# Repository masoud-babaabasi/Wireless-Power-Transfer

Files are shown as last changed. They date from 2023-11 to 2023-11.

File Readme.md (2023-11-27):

# A Wireless Power Transfer System
This is my master's degree project. The purpose of this project was to implement a wireless power transfer for a moving object for distances between 2 to 5 centimeters. This system also should compensate for angular misalignment in which the receiver coil plane has steep angles with the transmitting coils plane. All the coils for this project were implemented on PCB.
An array of 7 hexagon coils makes up the transmitting module. Each transmitter coil has a diameter of 5 centimeters and the receiver coil is a 3-centimeter square coil. For a better quality factor of the coils, the PCB coils are 2oz (70um) copper. 

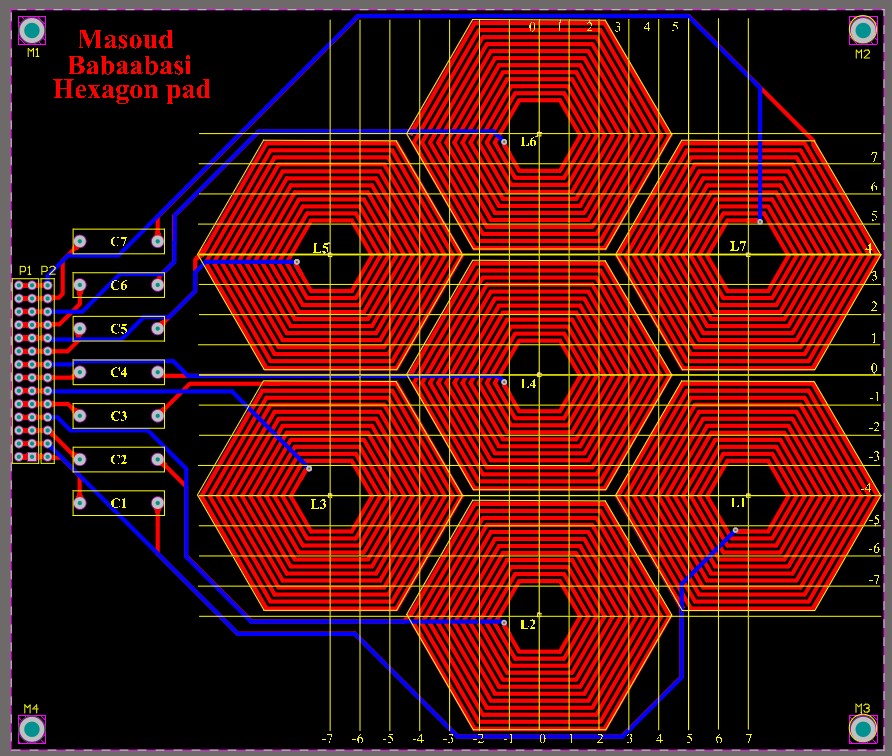
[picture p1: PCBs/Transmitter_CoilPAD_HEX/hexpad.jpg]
transmitter array


Painting all the coils in Altium Designer by hand is exhausting and complicated and making changes is even harder. So to automate routing, I used the Altium scripting feature. In Altium, you can write code in [DelphiScript](https://www.altium.com/documentation/altium-designer/writing-scripts) (*.pas), which is basically Pascal language. The Altium scrip project is in the `PCBs/Coil_drawing_script` folder. I have written several functions that draw different kinds of coils in a PCB document. In the picture below you can see some output examples of this script. With this script changing the parameters of the PCB coil such as width, spacing, number of turns, and output diameter of the coils is done very easily. You can access the functions in the `coil_script.pas` file.
```pascal
Procedure PlacePCBObjects;
Var
 CCW : Integer;
 L :  Integer;
 H :  Integer;
 w :  Integer;
 N :  Integer;
 s :  Integer;
 dis  : Integer;
Begin
    (*create a new pcb document *)
    WorkSpace := GetWorkSpace;
    If WorkSpace = Nil Then Exit;
    Workspace.DM_CreateNewDocument('PCB');

    If PCBServer = Nil Then Exit;
    Board := PCBServer.GetCurrentPCBBoard;
    If Board = Nil then exit;
    dis := 60;
    (* Place new PCB objects*)
     coilSpiralCW(50 , 5 , 0.9 , 0.3, dis , dis,eTopLayer,1);
     coilSpiralCCW(50 , 15 , 1.2 , 0.25, dis * 2 ,dis,eBottomLayer,1);
     coilHexagonCW(50 , 21 , 1 , 0.35, dis  * 3,dis ,eTopLayer ,1);
     CCW := 0;
     coilNside(4, 50 ,15 , 1 , 0.35, dis  * 4,dis ,CCW,Pi/4,eTopLayer , 1);
     coilSpiral(15 ,10 , 1 , 0.35, 1 ,dis  * 5,dis ,CCW , 0 ,eTopLayer , 1);
     CCW := 1;
     coilNside(5, 50 ,15 , 1 , 0.35, dis  ,dis * 2 ,CCW,7*pi/10,eTopLayer , 1);
     L := 50;
     N := 8;
     w := 1;
     s := 0.35;
     H := ( L - ( w + s ))/2 ;
     coilRECT_CW(L , H , N , w , s , dis * 2 ,dis * 2 , 1, eTopLayer , 1);
     coilRECT_CW(L , H , N , w , s , dis * 2 ,dis * 2 + H  + w + s  , 4 ,eTopLayer , 1);

     coilRECT_CCW(H , L , N , w , s, dis * 2 - (H+w+s)/2 ,dis * 2 + (H+w+s)/2 , 2 ,eBottomLayer , 1);
     coilRECT_CCW(H , L , N , w , s, dis * 2 - (H+w+s)/2 + H  + w + s ,dis * 2 + (H+w+s)/2, 1 ,eBottomLayer , 1);
     
     L := 30;
     N := 3;
     w := 3;
     coilRECT_CW(L , L , N , w , s , dis * 3 ,dis * 2 , 1, eTopLayer , 1);

    (* Refresh PCB workspace *)
    ResetParameters;
    AddStringParameter('Action', 'All');
    RunProcess('PCB:Zoom');
End;
```

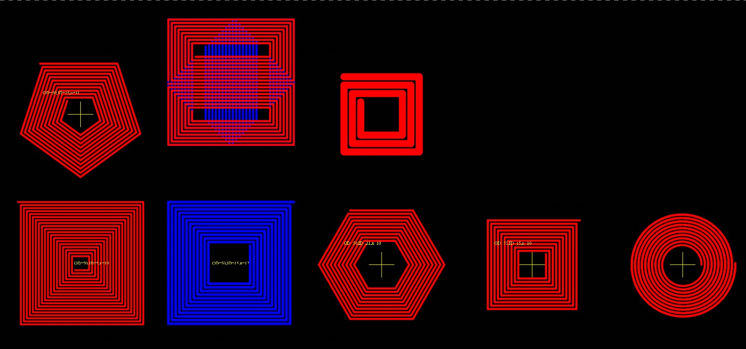
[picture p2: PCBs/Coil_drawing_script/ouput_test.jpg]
coils_altium


For driving the transmitter coils, 7 independent class D power amplifiers are implemented. The clock signals of these amplifiers are generated by an STM32F429 running at 180 MHz. Fourteen clock signals are produced and all of the amplifiers can be controlled independently.

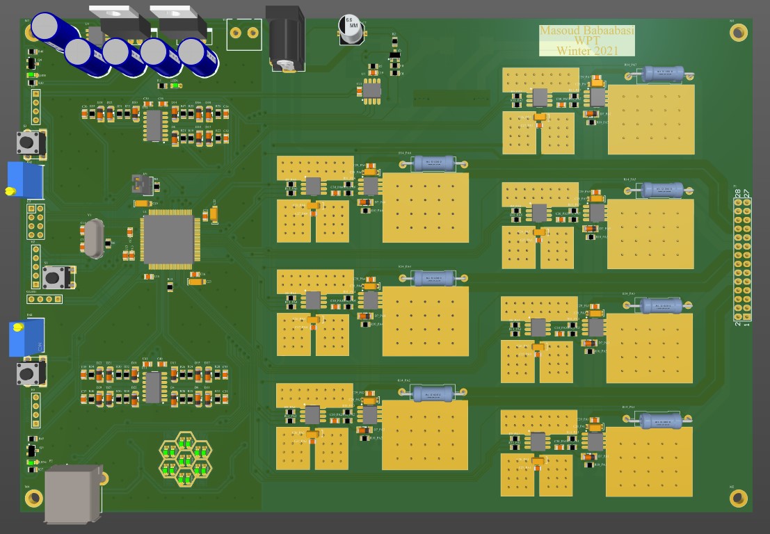
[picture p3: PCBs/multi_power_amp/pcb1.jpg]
power amps


On the receiver module, an ESP32 measures the voltage and current of the receiver circuit and transmits the data over Bluetooth Low Energy (BLE) to the transmitter module.

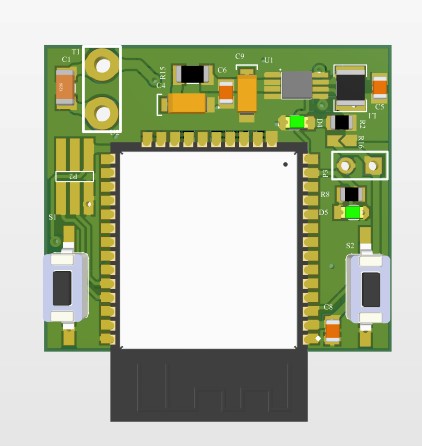
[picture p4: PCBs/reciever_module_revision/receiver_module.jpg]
receiver


ALL the coding for the transmitter module STM32F429 is done in Keil IDE. Four timers are used and all of them are configured to be in a slave-master situation which guarantees the synchronization of the clock signal.

A closed-loop algorithm is developed in Matalb to control the transmitter module based on data received over BLE.

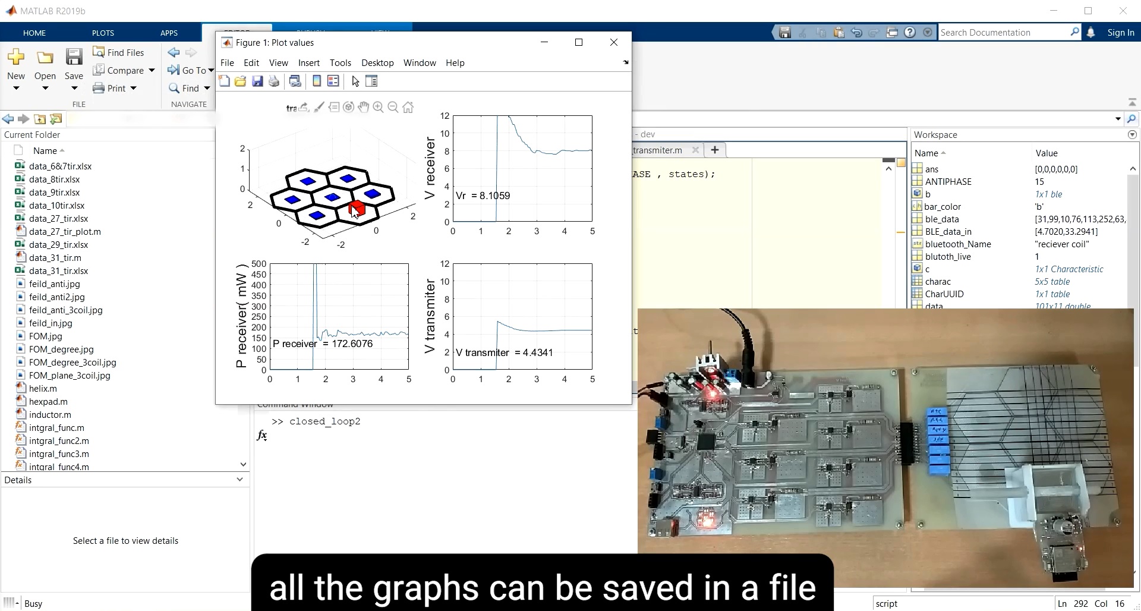
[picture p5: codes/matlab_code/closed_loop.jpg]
closed loop


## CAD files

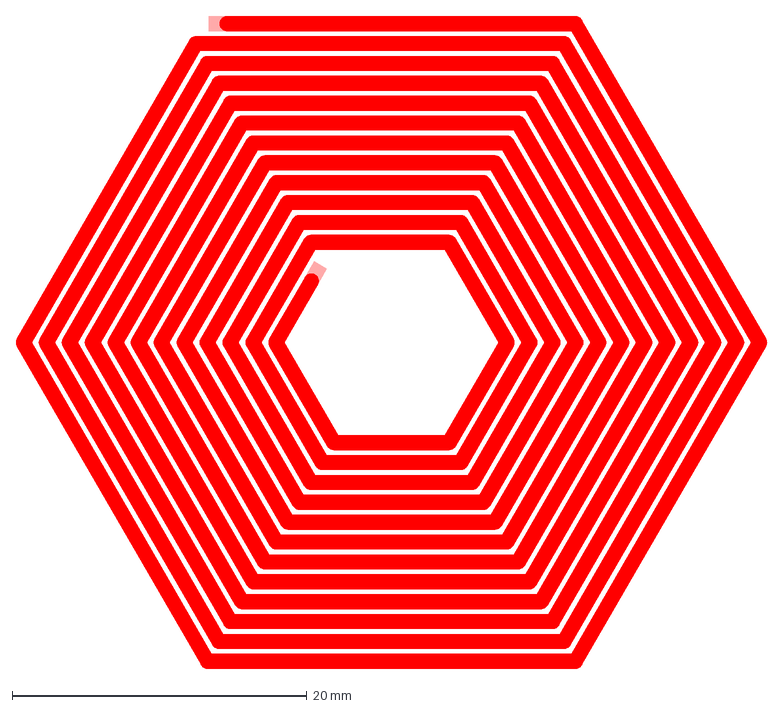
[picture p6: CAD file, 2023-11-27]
PCBs/Transmitter_CoilPAD_HEX/coil_hex.DXF
51.0 x 44.3 mm

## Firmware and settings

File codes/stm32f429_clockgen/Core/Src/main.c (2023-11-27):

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
/* Includes ------------------------------------------------------------------*/
#include "main.h"

ADC_HandleTypeDef hadc1;

SPI_HandleTypeDef hspi2;
SPI_HandleTypeDef hspi3;

TIM_HandleTypeDef htim1;
TIM_HandleTypeDef htim2;
TIM_HandleTypeDef htim3;
TIM_HandleTypeDef htim4;
TIM_HandleTypeDef htim5;
TIM_HandleTypeDef htim8;

UART_HandleTypeDef huart5;
UART_HandleTypeDef huart7;

/* USER CODE BEGIN PV */
#define RED 1
#define GREEN 0
#define ch1_2 1
#define ch3_4 3
#define INPHASE 1
#define OFF 0
#define ANTIPHASE -1
#define SHORTCIRCUIT 0
#define OPENCIRCUIT 1
	
TIM_TypeDef  *timers[7] = {TIM1,TIM2,TIM4,TIM4,TIM3,TIM3,TIM2};
const uint8_t channels[7] ={1,3,1,3,1,3,1};
uint16_t freq = 65;
uint8_t deadtime = 8;
float voltage = 4;
int8_t transmiter_state[7]={OFF,OFF,OFF,OFF,OFF,OFF,OFF};
uint16_t LEDs_state = 0;
uint8_t flags = 6;
//FATFS USBDISKFatFs;           /* File system object for USB disk logical drive */
//FIL MyFile;                   /* File object */
//char USBDISKPath[4];          /* USB Host logical drive path */
//USBH_HandleTypeDef hUSBHost; /* USB Host handle */
//static void MSC_Application(void);
//extern ApplicationTypeDef Appli_state;
char buff[5];
char received_flag = 0;
/* USER CODE END PV */

void SystemClock_Config(void);
static void MX_GPIO_Init(void);
static void MX_ADC1_Init(void);
static void MX_SPI2_Init(void);
static void MX_SPI3_Init(void);
static void MX_TIM1_Init(void);
static void MX_TIM2_Init(void);
static void MX_TIM3_Init(void);
static void MX_TIM4_Init(void);
static void MX_UART5_Init(void);
static void MX_UART7_Init(void);
static void MX_TIM5_Init(void);
static void MX_TIM8_Init(void);
/* USER CODE BEGIN PFP */
void timers_init();
void setRegVoltage(float Vo);
void resetLEDs();
void setLEDs(uint8_t COL, uint8_t NUM , uint8_t ON_OFF );
void set_frequency(int f);
void PWM_SET(TIM_HandleTypeDef* timer, uint8_t channel ,int8_t phase,int f,uint8_t deadtime);
void transmiter(uint8_t num,int8_t state , uint8_t HighZ);
/* USER CODE END PFP */

/* USER CODE BEGIN 0 */
	union transmit_data
    {
    uint16_t ADCValue[7];
    uint8_t TXdata[14];
    }TData;

/* USER CODE END 0 */

/**
  * @brief  The application entry point.
  * @retval int
  */
int main(void)
{
  /* MCU Configuration--------------------------------------------------------*/

  /* Reset of all peripherals, Initializes the Flash interface and the Systick. */
  HAL_Init();

  /* Configure the system clock */
  SystemClock_Config();

  /* Initialize all configured peripherals */
  MX_GPIO_Init();
  MX_ADC1_Init();
  MX_SPI2_Init();
  MX_SPI3_Init();
  MX_TIM1_Init();
  MX_TIM2_Init();
  MX_TIM3_Init();
  MX_TIM4_Init();
  MX_UART5_Init();
  MX_UART7_Init();
  MX_TIM5_Init();
  MX_TIM8_Init();
  /* USER CODE BEGIN 2 */
	resetLEDs();
//	__HAL_RCC_TIM2_CLK_ENABLE();
//	TIM2->CR1 = (1<<0)|(1<<5)|(1<<6);
//	TIM2->CCMR1 = (1<<5)|(1<<6)|(1<<14)|(1<<13);
//	TIM2->CCER = (1<<0)|(1<<4);
//	TIM2->ARR = freq;
//	TIM2->CCR1 = (freq/2)-5;
//	TIM2->CCR2 = (freq/2)+5;
//	__HAL_RCC_GPIOB_CLK_ENABLE();
//  __HAL_RCC_GPIOA_CLK_ENABLE();
//	GPIO_InitTypeDef GPIO_InitStruct = {0};
//	GPIO_InitStruct.Pin = GPIO_PIN_3;
//    GPIO_InitStruct.Mode = GPIO_MODE_AF_PP;
//    GPIO_InitStruct.Pull = GPIO_NOPULL;
//    GPIO_InitStruct.Speed = GPIO_SPEED_FREQ_LOW;
//    GPIO_InitStruct.Alternate = GPIO_AF1_TIM2;
//    HAL_GPIO_Init(GPIOB, &GPIO_InitStruct);

//    GPIO_InitStruct.Pin = GPIO_PIN_15;
//    GPIO_InitStruct.Mode = GPIO_MODE_AF_PP;
//    GPIO_InitStruct.Pull = GPIO_NOPULL;
//    GPIO_InitStruct.Speed = GPIO_SPEED_FREQ_LOW;
//    GPIO_InitStruct.Alternate = GPIO_AF1_TIM2;
//    HAL_GPIO_Init(GPIOA, &GPIO_InitStruct);
	//RCC->APB1ENR = RCC->APB1ENR |(uint32_t)(1<<0);
	
	
	
//	for(int i=1 ; i<=7 ; i++) {
//		if(i>1) setLEDs(RED,i-1,0);
//		setLEDs(RED,i,1);
//		HAL_Delay(100);
//	}
//	setLEDs(RED,7,0);
//	for(int i=1 ; i<=7 ; i++){
//		if(i>1) setLEDs(GREEN,i-1,0);
//		setLEDs(GREEN,i,1);
//		HAL_Delay(100);
//	}
//	setLEDs(GREEN,7,0);
  /* USER CODE END 2 */

  /* Infinite loop */
  /* USER CODE BEGIN WHILE */
	//int i;
	timers_init();
	HAL_GPIO_WritePin(REG_ON_GPIO_Port,REG_ON_Pin,GPIO_PIN_SET);
	HAL_GPIO_WritePin(POT_CS_GPIO_Port,POT_CS_Pin,GPIO_PIN_SET);
	HAL_Delay(100);
	setRegVoltage(4);
	/*for(i=3;i<=12;i++) {
		setRegVoltage(i);
		HAL_Delay(500);
	}*/
	//PWM_SET(&htim4 ,ch3_4 , ANTIPHASE ,64 , 7);
	//PWM_SET(&htim2 ,ch3_4 , INPHASE ,64 , 7);
	/*for(int i =1 ; i <= 7 ; i++){
			transmiter(i,ANTIPHASE);
		if(i>1) transmiter(i-1,OFF);
		HAL_Delay(2000);
	}*/
	//HAL_TIM_Base_Stop(&htim1);
	//HAL_TIM_Base_Stop(&htim2);
	//HAL_TIM_Base_Stop(&htim3);
	//HAL_TIM_Base_Stop(&htim4);
	HAL_Delay(200);
	//transmiter(2,INPHASE);
	HAL_Delay(20);
	transmiter(6,ANTIPHASE,OPENCIRCUIT);
//	char tx_state = 'S';
//	buff[0] = 'S';
	set_frequency(102);
	//transmiter(6,ANTIPHASE);
	//transmiter(7,ANTIPHASE);
	HAL_TIM_PWM_Start(&htim1, TIM_CHANNEL_1);
	HAL_TIM_PWM_Start(&htim1, TIM_CHANNEL_2);	
	//HAL_TIM_Base_Start(&htim1);
	TIM1->CR1 |= (1<<0);
	TIM5->CR1 |= (1<<0);
	
	HAL_TIM_Base_Start(&htim8);
	HAL_TIM_Base_Start(&htim1);
	HAL_TIM_PWM_Start(&htim1, TIM_CHANNEL_1);
	HAL_TIM_PWM_Start(&htim1, TIM_CHANNEL_2);	
	//HAL_TIM_PWM_Start(&htim4, TIM_CHANNEL_3);
	//HAL_TIM_PWM_Start(&htim4, TIM_CHANNEL_4);		

	float v = 4;
	
	uint16_t f=0;
	//unsigned int ADCValue[9];
	uint8_t i=0;
	//Appli_state = APPLICATION_START;
	HAL_UART_Receive_IT(&huart5,(uint8_t *)buff, 2);
	//void *packetADD = &(ADCValue[0]);
  while (1)
  {
		/*HAL_GPIO_TogglePin(LED1_GPIO_Port,LED1_Pin);
		HAL_Delay(500);
		HAL_GPIO_TogglePin(LED2_GPIO_Port,LED2_Pin);
		HAL_Delay(500);*/
		/*setRegVoltage(v);
		if(f){
			v = v + 0.5;
			if(v==10) f=0;
		}
		else{
			v = v - 0.5;
			if(v==3) f=1;
		}
		HAL_Delay(500);*/
/*************** ADC start conversion*******************************/
		/*HAL_ADC_Start(&hadc1);
		for(i=0;i<10;i++){
			if (HAL_ADC_PollForConversion(&hadc1, 100) == HAL_OK){
					TData.ADCValue[i] = HAL_ADC_GetValue(&hadc1);
			}
		}
		HAL_UART_Transmit (&huart5, TData.TXdata ,2*7,10);*/
		//HAL_Delay(10);

/**************UART input data interpatation*************************/		
		if(received_flag){
				received_flag = 0;
				if( buff[0] == 'f' || buff[0] == 'F' ){
					freq = ( (uint8_t)buff[1] );
					set_frequency(freq);
				}else if( buff[0] == 'v' || buff[0] == 'V' ){
					voltage = (( uint8_t)buff[1] ) * 10 / 255.0 + 1.9;
					setRegVoltage( voltage );
				}
				else if( buff[0] == 't' || buff[0] == 'T' ){
					flags = (( uint8_t)buff[1] )  & ( 0x0f );
					transmiter_state[ flags - 1 ] = (int8_t) ( ( uint8_t)buff[1]  & ( 0xf0 ) ) >> 4 ;
					transmiter( flags , transmiter_state[ flags - 1 ] , OPENCIRCUIT );
				}
				else if( buff[0] == 'S' && buff[1] == 'C' ){ //start conversion command
					HAL_ADC_Start(&hadc1);
					for(i=0;i<10;i++){
						if (HAL_ADC_PollForConversion(&hadc1, 100) == HAL_OK){
								TData.ADCValue[i] = HAL_ADC_GetValue(&hadc1);
						}
					}
					HAL_UART_Transmit (&huart5, TData.TXdata ,2*7,10);
				}
}
/*******************frequency setting**********************************/
//		f = TData.ADCValue[3] /(2047.0) * 80 + 50 ;
//		if( f != freq){
//			freq = f;
////			HAL_TIM_Base_Stop(&htim8);
////			HAL_TIM_Base_Stop(&htim5);
////			HAL_TIM_Base_Stop(&htim1);
////			HAL_TIM_Base_Stop(&htim2);
////			HAL_TIM_Base_Stop(&htim3);
////			HAL_TIM_Base_Stop(&htim4);
//			set_frequency(f);
////			HAL_TIM_Base_Start(&htim8);
////			HAL_TIM_Base_Start(&htim5);
//		}

/********************************voltage set****************************/
//		v = TData.ADCValue[4] / (2047.0)  * 8.0  + 4.0;
//		if(v != voltage ) {
//			voltage = v;
//			setRegVoltage(v);
//		}
		HAL_Delay(10);
		
/********************** transmiter number set *************************/
//		if( HAL_GPIO_ReadPin(PB2_GPIO_Port,PB2_Pin) == GPIO_PIN_RESET){
//			flags++;
//			if(flags>= 8 ) flags =6;
//			transmiter(flags,ANTIPHASE,OPENCIRCUIT);
//			/*if(flags == 0 ) {
//				transmiter(7,ANTIPHASE);
//				flags =1;
//			}
//			else if(flags == 1 ) {
//				transmiter(7,INPHASE);
//				flags =2;
//			}else if(flags == 2 ) {
//				transmiter(7,OFF);
//				flags =0;
//			}*/
//			/*flags++;
//			if(flags==8)flags = 1;
//			if(flags == 1) transmiter(7,OFF);
//			else transmiter(flags-1,OFF);
//			transmiter(flags,ANTIPHASE);*/
//			HAL_Delay(300);
//		}
/******************* transmiter state set*****************************/
//		if( HAL_GPIO_ReadPin(PB1_GPIO_Port,PB1_Pin) == GPIO_PIN_RESET){
//			int8_t st = transmiter_state[flags-1];
////			st++;
////			if(st == 2) st = -1;
//			st--;
//			if(st <= -2) st = 1;
//			transmiter(flags,st,OPENCIRCUIT);
//			HAL_Delay(300);	
//		}
    /* USER CODE END WHILE */

    /* USER CODE BEGIN 3 */
  }
  /* USER CODE END 3 */
}

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
/* USER CODE BEGIN 4 */
/********************************************************************************************/
void timers_init(){
	TIM1->CCER &= ~((1 << 0) | (1 << 4) | (1 << 8) | (1 << 12) );
	TIM2->CCER &= ~((1 << 0) | (1 << 4) | (1 << 8) | (1 << 12) );
	TIM3->CCER &= ~((1 << 0) | (1 << 4) | (1 << 8) | (1 << 12) );
	TIM4->CCER &= ~((1 << 0) | (1 << 4) | (1 << 8) | (1 << 12) );
	
	TIM1->CR1 |= (1<<0);
	TIM2->CR1 |= (1<<0);
	TIM3->CR1 |= (1<<0);
	TIM4->CR1 |= (1<<0);
}
/********************************************************************************************/
void setRegVoltage(float Vo){
	uint16_t pData;
	//pData = 0x11;
//	if( Vo >=2.717 && Vo <= 12) pData = 1.482/(Vo-1.235)*256.00;
//	else if( Vo < 2.717 ) pData = 255;
//	else if( Vo > 12 ) pData = 35;
	if( Vo >=1.9 && Vo <= 12) pData = 4.7*1.23*256.0/10.0/(Vo-1.23);
	else if( Vo < 1.9 ) pData = 255;
	else if( Vo > 12 ) pData = 14;
	pData = pData | (uint16_t)(0x11 << 8) ;
	HAL_GPIO_WritePin(POT_CS_GPIO_Port,POT_CS_Pin,GPIO_PIN_RESET);
	HAL_SPI_Transmit(&hspi2,(uint8_t *)&pData,1,100);
	HAL_GPIO_WritePin(POT_CS_GPIO_Port,POT_CS_Pin,GPIO_PIN_SET);
  /* USER CODE END UART7_Init 2 */

}

/********************************************************************************************/
void resetLEDs(){
	uint8_t LED_data1 = 0x00;
	HAL_SPI_Transmit(&hspi3,(uint8_t *)&LED_data1,1,100);
	HAL_SPI_Transmit(&hspi3,(uint8_t *)&LED_data1,1,100);
	HAL_Delay(1);
	HAL_GPIO_WritePin(REG_clk_GPIO_Port,REG_clk_Pin,GPIO_PIN_SET);
	HAL_Delay(1);
	HAL_GPIO_WritePin(REG_clk_GPIO_Port,REG_clk_Pin,GPIO_PIN_RESET);
}
/********************************************************************************************/
void setLEDs(uint8_t COL, uint8_t NUM , uint8_t ON_OFF ){
		uint16_t d = 0 ;
		if( NUM <= 7 && NUM >= 1 && (COL == RED || COL == GREEN)){
			d = 1 << (LED_POS[NUM-1]*2 + COL);
			if(ON_OFF == 1) LEDs_state |= d;
			else if(ON_OFF == 0) LEDs_state &= ~d;			 
			uint8_t LED_data1 = LEDs_state & 0xff;
			uint8_t LED_data2 = LEDs_state >> 8;
			HAL_SPI_Transmit(&hspi3,&LED_data1,1,100);
			HAL_SPI_Transmit(&hspi3,&LED_data2,1,100);
			HAL_Delay(1);
			HAL_GPIO_WritePin(REG_clk_GPIO_Port,REG_clk_Pin,GPIO_PIN_SET);
			HAL_Delay(1);
			HAL_GPIO_WritePin(REG_clk_GPIO_Port,REG_clk_Pin,GPIO_PIN_RESET);
		}
}
/********************************************************************************************/
void set_frequency(int f){
	TIM1->ARR = f;
	TIM2->ARR = f;
	TIM3->ARR = f;
	TIM4->ARR = f;
	for(int i=0;i<7;i++){
		if( channels[i] == ch1_2){
			timers[i]->CCR1 = (uint16_t)(f / 2)-transmiter_state[i]*deadtime;
			timers[i]->CCR2 = (uint16_t)(f / 2)+ transmiter_state[i]*deadtime;
		}else if( channels[i] == ch3_4){
			timers[i]->CCR3 = (uint16_t)(f / 2)- transmiter_state[i]*deadtime;
			timers[i]->CCR4 = (uint16_t)(f / 2)+ transmiter_state[i]*deadtime;
		}
	}
}
/********************************************************************************************/
void PWM_SET(TIM_HandleTypeDef* timer,uint8_t channel ,int8_t phase ,int f,uint8_t deadtime)
{
//	timer->Init.Period = f;
//	HAL_TIM_PWM_Init(timer);
//	TIM_OC_InitTypeDef sConfigOC = {0};
//	sConfigOC.OCPolarity = TIM_OCPOLARITY_HIGH;
//  sConfigOC.OCFastMode = TIM_OCFAST_ENABLE;

	//sConfigOC.Pulse = (uint16_t)(f / 2);

//	if( phase == INPHASE) sConfigOC.OCMode = TIM_OCMODE_PWM1;
//  else if( phase == ANTIPHASE) sConfigOC.OCMode = TIM_OCMODE_PWM2;
//  sConfigOC.Pulse = (int)(f / 2) - (phase)*deadtime;
//	if(channel == ch1_2) HAL_TIM_PWM_ConfigChannel(timer, &sConfigOC, TIM_CHANNEL_1);
//	else if(channel == ch3_4) HAL_TIM_PWM_ConfigChannel(timer, &sConfigOC, TIM_CHANNEL_3);
//  sConfigOC.Pulse = (int)(f / 2) + (phase)*deadtime;
//	if(channel == ch1_2) HAL_TIM_PWM_ConfigChannel(timer, &sConfigOC, TIM_CHANNEL_2);
//	else if(channel == ch3_4) HAL_TIM_PWM_ConfigChannel(timer, &sConfigOC, TIM_CHANNEL_4);
  	HAL_TIM_MspPostInit(timer);
}
/********************************************************************************************/
void transmiter(uint8_t num,int8_t state , uint8_t HighZ)
{
	uint16_t temp;
	if(state == INPHASE ){
			if(channels[num-1] == ch1_2){
			timers[num-1]->CCER &= ~((1 << 0) | (1 << 4));
			timers[num-1]->CCMR1 |= ((1<<5)|(1<<6)|(1<<13)|(1<<14));
			timers[num-1]->CCMR1 &= ~((1<<4)|(1<<12));//pwm mode1
			timers[num-1]->CCR1 = (uint16_t)(freq / 2)- state*deadtime;
			timers[num-1]->CCR2 = (uint16_t)(freq / 2)+ state*deadtime;
			timers[num-1]->CCER |= ((1 << 0) | (1 << 4));//output enable
			}else if(channels[num-1] == ch3_4){
			timers[num-1]->CCER &= ~((1 << 8) | (1 << 12));
			timers[num-1]->CCMR2 |= ((1<<5)|(1<<6)|(1<<13)|(1<<14));
			timers[num-1]->CCMR2 &= ~((1<<4)|(1<<12));//pwm mode1
			timers[num-1]->CCR3 = (uint16_t)(freq / 2)- state*deadtime;
			timers[num-1]->CCR4 = (uint16_t)(freq / 2)+ state*deadtime;
			timers[num-1]->CCER |= ((1 << 8) | (1 << 12));//output enable
			}
			setLEDs(RED , num , 1);
			setLEDs(GREEN , num , 0);
	}else if(state == ANTIPHASE ){
		 if(channels[num-1] == ch1_2){
			timers[num-1]->CCER &= ~((1 << 0) | (1 << 4));
			timers[num-1]->CCMR1 |= ((1<<4)|(1<<5)|(1<<6)|(1<<12)|(1<<13)|(1<<14));//pwm mode2
			timers[num-1]->CCR1 = (uint16_t)(freq / 2)- state*deadtime;
			timers[num-1]->CCR2 = (uint16_t)(freq / 2)+ state*deadtime;
			timers[num-1]->CCER |= ((1 << 0) | (1 << 4));//output enable
			}else if(channels[num-1] == ch3_4){
			timers[num-1]->CCER &= ~((1 << 8) | (1 << 12));
			timers[num-1]->CCMR2 |= ((1<<4)|(1<<5)|(1<<6)|(1<<12)|(1<<13)|(1<<14));//pwm mode2
			timers[num-1]->CCR3 = (uint16_t)(freq / 2)- state*deadtime;
			timers[num-1]->CCR4 = (uint16_t)(freq / 2)+ state*deadtime;
			timers[num-1]->CCER |= ((1 << 8) | (1 << 12));//output enable
			}
			setLEDs(GREEN , num , 1);
			setLEDs(RED , num , 0);
	}else if(state == OFF){
		if(channels[num-1] == ch1_2){
			timers[num-1]->CCER &= ~((1 << 0) | (1 << 4)); // output disable
			timers[num-1]->CCMR1 |= ((1<<6)|(1<<14));//output forced mode inactive level ch1 inactive level ch2(gate drive is inverted- nmos is ch2)
			timers[num-1]->CCMR1 &= ~((1<<4)|(1<<5)|(1<<12)|(1<<13));
			if( HighZ == SHORTCIRCUIT ) timers[num-1]->CCER |= ((1 << 0) | (1 << 4));//output enable
		}
		if(channels[num-1] == ch3_4){
			timers[num-1]->CCER &= ~((1 << 8) | (1 << 12));
			timers[num-1]->CCMR2 |= ((1<<6)|(1<<14));//output forced mode inactive level ch1 inactive level ch2(gate drive is inverted- nmos is ch2)
			timers[num-1]->CCMR2 &= ~((1<<4)|(1<<5)|(1<<12)|(1<<13));
			if( HighZ == SHORTCIRCUIT ) timers[num-1]->CCER |= ((1 << 8) | (1 << 12));//output enable
		}
		setLEDs(RED , num , 0);
		setLEDs(GREEN , num , 0);
	}
	transmiter_state[num-1] = state;
	
}

void HAL_UART_RxCpltCallback(UART_HandleTypeDef *huart)
{
	//char buff2[5]="done\n";
  HAL_UART_Receive_IT(&huart5,(uint8_t *)buff, 2);
	received_flag = 1;
//	HAL_UART_Transmit (&huart5,(uint8_t *)buff ,5,500);	
//	if(buff[0] == 'I'){
//		freq = 92;
////		set_frequency(freq);
////		transmiter(6,ANTIPHASE,OPENCIRCUIT);
////		transmiter(7,ANTIPHASE,OPENCIRCUIT);
////		HAL_UART_Transmit (&huart5,(uint8_t *)buff2 ,5,50);		
//	}else if(buff[0] == 'A'){
//		freq = 97;
////		set_frequency(freq);
////		transmiter(6,ANTIPHASE,OPENCIRCUIT);
////		transmiter(7,INPHASE,OPENCIRCUIT);		
////		HAL_UART_Transmit (&huart5,(uint8_t *)buff2 ,5,50);	
//	}else if(buff[0] == 'S'){
//		freq = 95;
////		set_frequency(freq);
////		transmiter(6,ANTIPHASE,OPENCIRCUIT);
////		transmiter(7,OFF,OPENCIRCUIT);
////HAL_UART_Transmit (&huart5,(uint8_t *)buff2 ,5,50);			
//	}
}
/* USER CODE END 4 */
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


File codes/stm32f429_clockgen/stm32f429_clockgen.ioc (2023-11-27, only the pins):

Mcu.UserName=STM32F429VITx
PA0/WKUP.Signal=ADCx_IN0
PA1.Signal=ADCx_IN1
PA13.Signal=SYS_JTMS-SWDIO
PA14.Signal=SYS_JTCK-SWCLK
PA15.Signal=S_TIM2_CH1_ETR
PA2.Signal=ADCx_IN2
PA3.Signal=ADCx_IN3
PA5.GPIO_Label=LED2
PA5.Signal=GPIO_Output
PA6.Signal=ADCx_IN6
PA7.Signal=ADCx_IN7
PB0.Signal=ADCx_IN8
PB1.Signal=ADCx_IN9
PB10.Signal=S_TIM2_CH3
PB11.Signal=S_TIM2_CH4
PB12.Signal=GPIO_Output
PB3.Signal=S_TIM2_CH2
PB4.GPIO_Label=PB1
PB4.Signal=GPIO_Input
PB5.GPIO_Label=REG_ON
PB5.Signal=GPIO_Output
PB8.Signal=S_TIM4_CH3
PB9.Signal=S_TIM4_CH4
PC0.Signal=ADCx_IN10
PC1.Signal=ADCx_IN11
PC10.Signal=SPI3_SCK
PC11.GPIO_Label=REG_clk
PC11.Signal=GPIO_Output
PC12.Signal=UART5_TX
PC2.Signal=ADCx_IN12
PC3.Signal=SPI2_MOSI
PC6.Signal=S_TIM3_CH1
PC7.Signal=S_TIM3_CH2
PC8.Signal=S_TIM3_CH3
PC9.Signal=S_TIM3_CH4
PD12.Signal=S_TIM4_CH1
PD13.Signal=S_TIM4_CH2
PD2.Signal=UART5_RX
PD3.Signal=SPI2_SCK
PD6.Signal=SPI3_MOSI
PE0.GPIO_Label=POT_CS
PE0.Signal=GPIO_Output
PE1.GPIO_Label=LED1
PE1.Signal=GPIO_Output
PE10.GPIO_Label=PB2
PE10.Signal=GPIO_Input
PE11.Signal=S_TIM1_CH2
PE13.Signal=S_TIM1_CH3
PE14.Signal=S_TIM1_CH4
PE7.Signal=UART7_RX
PE8.Signal=UART7_TX
PE9.Signal=S_TIM1_CH1
PH0/OSC_IN.Signal=RCC_OSC_IN
PH1/OSC_OUT.Signal=RCC_OSC_OUT

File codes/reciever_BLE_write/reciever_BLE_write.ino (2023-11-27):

/*
    Based on Neil Kolban example for IDF: https://github.com/nkolban/esp32-snippets/blob/master/cpp_utils/tests/BLE%20Tests/SampleWrite.cpp
    Ported to Arduino ESP32 by Evandro Copercini
*/

#include <BLEDevice.h>
#include <BLEUtils.h>
#include <BLEServer.h>
#include <BLE2902.h>

// See the following for generating UUIDs:
// https://www.uuidgenerator.net/

// use first channel of 16 channels (started from zero)
#define LEDC_CHANNEL_0     0

// use 13 bit precission for LEDC timer
#define LEDC_TIMER_13_BIT  13

// use 5000 Hz as a LEDC base frequency
#define LEDC_BASE_FREQ     5000

// fade LED PIN (replace with LED_BUILTIN constant for built-in LED)
#define LED_PIN            14
int brightness = 0;    // how bright the LED is
int fadeAmount = 5;    // how many points to fade the LED by
// Arduino like analogWrite
// value has to be between 0 and valueMax
void ledcAnalogWrite(uint8_t channel, uint32_t value, uint32_t valueMax = 255) {
  // calculate duty, 8191 from 2 ^ 13 - 1
  uint32_t duty = (8191 / valueMax) * min(value, valueMax);

  // write duty to LEDC
  ledcWrite(channel, duty);
}
#define m1    0.005294779116466
#define m2    0.005443435177539
#define v0_1  1.021101204819277
#define v0_2  1.038402146985962
#define Rsen 9.937
#define DELAYMS 30

int sen1,sen2; 
float v1 , v2;
int i = 0;
int n = 1000;
uint32_t t1;
#define SERVICE_UUID        "4fafc201-1fb5-459e-8fcc-c5c9c331914b"
#define CHARACTERISTIC_UUID "beb5483e-36e1-4688-b7f5-ea07361b26a8"
bool deviceConnect = false;
BLEServer *pServer;
BLEService *pService;
BLECharacteristic *pCharacteristic;
BLEAdvertising *pAdvertising;

class MyCallbacks: public BLECharacteristicCallbacks {
  void onConnect(BLEServer *pServer){
    deviceConnect = true;
  }
  void onDisconnect(BLEServer *pServer){
    deviceConnect = false;
  }
//    void onWrite(BLECharacteristic *pCharacteristic) {
//      std::string value = pCharacteristic->getValue();
//
//      if (value.length() > 0) {
//        Serial.println("*********");
//        Serial.print("New value: ");
//        for (int i = 0; i < value.length(); i++)
//          Serial.print(value[i]);
//
//        Serial.println();
//        Serial.println("*********");
//      }
//    }
};

void setup() {
  //setCpuFrequencyMhz(80);
  Serial.begin(115200);
  Serial.println("BLE startting");
  ledcSetup(LEDC_CHANNEL_0, LEDC_BASE_FREQ, LEDC_TIMER_13_BIT);
  ledcAttachPin(LED_PIN, LEDC_CHANNEL_0);
/*Serial.println("1- Download and install an BLE scanner app in your phone");
  Serial.println("2- Scan for BLE devices in the app");
  Serial.println("3- Connect to (reciever coil)");
  Serial.println("4- Go to CUSTOM CHARACTERISTIC in CUSTOM SERVICE and write something");
  Serial.println("5- See the magic =)");*/
  t1 = millis();
  BLEDevice::init("ESP32");
  pServer = BLEDevice::createServer();
  pService = pServer->createService(SERVICE_UUID);
  pCharacteristic = pService->createCharacteristic(
                                         CHARACTERISTIC_UUID,
                                         BLECharacteristic::PROPERTY_READ |
                                         BLECharacteristic::PROPERTY_WRITE
                                       );

  pCharacteristic->setCallbacks(new MyCallbacks());
  pCharacteristic->addDescriptor(new BLE2902());
  pCharacteristic->setValue("Start");
  pService->start();

//  pAdvertising = pServer->getAdvertising();
//  pAdvertising->start();
  BLEAdvertising *pAdvertising = BLEDevice::getAdvertising();
  pAdvertising->addServiceUUID(SERVICE_UUID);
  pAdvertising->setScanResponse(false);
  pAdvertising->setMinPreferred(0x0);  // set value to 0x00 to not advertise this parameter
  BLEDevice::startAdvertising();
  Serial.println("Waiting a client connection to notify...");
}

void loop() {
  if( millis() - t1 > DELAYMS ){
     // set the brightness on LEDC channel 0
    ledcAnalogWrite(LEDC_CHANNEL_0, brightness);
  
    // change the brightness for next time through the loop:
    brightness = brightness + fadeAmount;
  
    // reverse the direction of the fading at the ends of the fade:
    if (brightness <= 0 || brightness >= 255) {
      fadeAmount = -fadeAmount;
    }
    // wait for 30 milliseconds to see the dimming effect
    //delay(1); 
    t1 = millis();
  }
  delayMicroseconds(50);
  sen1 +=  analogRead(34);
  sen2 +=  analogRead(35);
  i++;
  if( i == n ){
    sen1 /= n ;
    sen2 /= n ;
    v1 = sen1 * m1 + v0_1;
    v2 = sen2 * m2 + v0_2;
    //Serial.printf("vin=%5.3f , Iin = %5.3fmA\n",v1 , (v2 - v1)*1000 );
    /******/
    //if(deviceConnect){
    //char str[30];
    //sprintf(str,"vin=%5.3f , Iin = %5.3fmA\n",v1 , (v1 - v2)/Rsen*1000 );
    //pCharacteristic->setValue(str);
//    char buf[3];
//    buf[0] = (uint8_t)(( v1 - 3.0 ) * 255.0 / (17.0 - 3.0)) ;
//    float Iin = (v1 - v2)/Rsen*1000;
//    buf[1] = (uint8_t)(( Iin - 10.0 ) * 255.0 / (70.0 - 10.0)) ;
//    buf[2] = '\n';
char buf[13] = "Data_is:";
    buf[9] = (uint8_t)(( v1 - 3.0 ) * 255.0 / (17.0 - 3.0)) ;
    float Iin = (v1 - v2)/Rsen*1000;
    buf[10] = (uint8_t)(( Iin - 10.0 ) * 255.0 / (70.0 - 10.0)) ;
    buf[11] = '\n';
    buf[12] = 0;
    pCharacteristic->setValue(buf);
     pCharacteristic->notify();
     //delay(10);
    //}
    /*****/
    i=0;
    sen1 = sen2 = 0;
  }
}

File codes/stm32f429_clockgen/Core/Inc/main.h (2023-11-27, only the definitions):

#define LED2_Pin GPIO_PIN_5
#define LED2_GPIO_Port GPIOA
#define PB2_Pin GPIO_PIN_10
#define PB2_GPIO_Port GPIOE
#define REG_clk_Pin GPIO_PIN_11
#define REG_clk_GPIO_Port GPIOC
#define PB1_Pin GPIO_PIN_4
#define PB1_GPIO_Port GPIOB
#define REG_ON_Pin GPIO_PIN_5
#define REG_ON_GPIO_Port GPIOB
#define POT_CS_Pin GPIO_PIN_0
#define POT_CS_GPIO_Port GPIOE
#define LED1_Pin GPIO_PIN_1
#define LED1_GPIO_Port GPIOE

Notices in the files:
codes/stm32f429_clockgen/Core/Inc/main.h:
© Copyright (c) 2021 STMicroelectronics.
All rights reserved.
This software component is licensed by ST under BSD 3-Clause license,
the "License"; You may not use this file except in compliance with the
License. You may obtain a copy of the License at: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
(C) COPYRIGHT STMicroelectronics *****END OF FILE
